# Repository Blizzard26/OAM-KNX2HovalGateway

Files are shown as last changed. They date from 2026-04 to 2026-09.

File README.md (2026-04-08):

# Hoval2KNXGateway

A KNX gateway for Hoval TopTronic systems, enabling integration between KNX home automation networks and Hoval CAN-based controllers.

It is a PlatformIO project and needs a working ETS 5.7 (or higher) installed on the same PC (at least for generating the required ETS files).

It uses some Modules from the OpenKNX project: OGM-Common, OFM-cnofigTransfer, OFM-FileTransferModule, OFM-LogicModule

## Description

This project implements a bridge between KNX protocol and Hoval's proprietary CAN-based communication protocol. It allows KNX devices to read and write parameters from Hoval TopTronic systems.

The gateway uses the Hoval Message Protocol over CAN bus at 50kbps, supporting both single and multi-part messages for comprehensive datapoint access.

## Supported Hardware

Currently supports

- Seeeduino XIAO RP2040 with a MCP2515 (and a support CAN Transceive, e.g. MCP2562). Make sure to electrically separate the KNX bus from the Hoval bus as the operate on different potentials.

## Software Requirements

- **PlatformIO**: For building and flashing the firmware
- **Git**: For cloning this repository
- **Arduino Framework**: Used via PlatformIO
- **Dependencies**:
  - KNX library (version 2.2.2+)
  - Seeed Arduino CAN library
  - Various OpenKNX modules

## Installation

1. Clone this repository and initialize submodules:
   ```bash
   git clone <repository-url>
   cd Hoval2KNXGateway
   git submodule update --init --recursive
   ```
   NOTE: In contrast to other OpenKNX Projects this project uses git submodule to pull in libraries instead of restore scripts and `dependencies.txt`.

2. Install PlatformIO if not already installed.

3. Install dependencies:
   ```bash
   pio lib install
   ```

## Building

Use the provided build scripts or PlatformIO directly:

### Development Build
```bash
scripts/Build-Release.ps1
```
Or use the VS Code task: `Build-Dev`

### Release Build
```bash
scripts/Build-Release.ps1 Release
```
Or use the VS Code task: `Build-Release`

### Configuration

- Configure KNX parameters using ETS (Engineering Tool Software)

### Monitoring

Connect to the serial port at 115200 baud for debug output and monitoring.

There are four new commands added:

- `hoval log message`: Log received and processed messages - header only.
- `hoval log messageData`: Log received and processed message - including (parsed) data.
- `hoval log filtered`: Log filtered message, i.e., messages not known to the decoder - header only.
- `hoval log filteredData`: Log filtered message - including raw data.

## Project Structure

- `src/`: Main source code
- `include/`: Header files and configuration
- `lib/`: Library dependencies and modules
- `docs/`: Protocol documentation (Hoval.adoc)
- `schematics/`: Hardware schematics in KiCad format
- `scripts/`: Build and utility scripts
- `test/`: Test files

## Documentation

Detailed protocol documentation is available in `docs/Hoval.adoc`, including:
- Message structure and addressing
- Function codes and datapoints
- Communication flow examples

## Contributing

1. Fork the repository
2. Create a feature branch
3. Make your changes
4. Test thoroughly
5. Submit a pull request

## License

GNU General Public License v3.0

## Support

For issues and questions:
- Check the debug logs via serial output
- Refer to the protocol documentation
- Ensure proper hardware connections

## Disclaimer

This software is provided as-is. Ensure compatibility with your specific Hoval system and KNX installation. Always backup configurations before making changes.

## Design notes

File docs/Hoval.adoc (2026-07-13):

= Hoval Message Protocol
:toc:
:toclevels: 4

== Overview
Hoval uses a CAN extended protocol with 50kbps as transport layer.
The session layer supports single and multi-part messages (messages consisting of several individual messages).

The Hoval Message Protocol is a CAN-based communication protocol with:

* 29-bit extended CAN identifiers (addressing)
* A message layer supporting:
  - Single messages (up to 8 bytes)
  - Multi-part messages (segmented payloads)
* A data model based on:
  - Function Code
  - Function Group
  - Function Number
  - Datapoint ID

Typical communication flow:

1. A device sends a request (e.g. read or write)
2. The target responds via broadcast
3. Messages may be single-frame or multi-part

Structure of a message:

`[Address (29 bit)] + [Payload (2–8 bytes)]`

Some information is not yet 100% clear. 
These parts are marked in #yellow#.

A lot of information can be found in the Modbus protocol description from Hoval (`TTE-GW-Modbus-datapoints.xlsx`). 

NOTE: This is not complete and there are many messages that are not documented.

=== Terminology

* Function Code: Defines the operation (read, write, etc.)
* Function Group: Logical grouping of datapoints
* Function Number: Sub-function within a group
* Datapoint ID: Unique identifier of a value
* Unit ID: Device identifier

Message Types:

* Single Message: Complete in one frame
* Multi-part Message:
  - Start Message
  - Intermediate Message(s)
  - End Message

=== Modbus Datapoints (from `TTE-GW-Modbus-datapoints.xlsx`)

*Modbus ID* +
Dec: 1 - 25610 +
Hex: 0x0001 - 0x640A +
Bits: 15

*Unit ID* +
Dec: 1 - 1160 +
Hex: 0x001 - 0x448 +
Bits: 11

*Function Group* +
Dec: 0 - 60 +
Hex: 0x00 - 0x3C +
Bits: 6

*Function Number* +
Dec: 0 - 254 +
Hex: 0x00 - 0xFE +
Bits: 8

*Datapoint ID* +
Dec: 0 - 40687 +
Hex: 0x0 - 0x9EEF +
Bits: 16

== Analysis of the message protocol

=== Address

The address consists of 29 bits (4 bytes) (Can extended protocol).

An address encodes:

* Sequence counter (multi-part only)
* Message type (single / multi-part)
* Sender Unit ID
* Target Unit ID

Example: `1F E0 42 08`

Structure (right to left):

* Bit 25 - 29: Multi-part message counter. This always starts at 0x1F (31) and counts down from there for multi-part messages.
** Messages with a 0 serve as timer messages/pings or similar.
* Bit 23-24: Message type:
** Bit 24 = 1: flag: last message in a multi-part message
** Bit 23 = 1: flag: first message in a multi-part message
* Bit 12 - 22: _Unit ID_ of the sender (device number + device type offset)
* Bit 11 - 1: _Unit ID_ of the target (device number + device type offset; see `TTE-GW-Modbus-datapoints.xlsx`) or `0x7FF` for broadcast

.Address Structure
====
Address: `1F E0 42 08`

[width="100%",cols="17%,17%,16%,17%,16%,17%",options="header",]
|===
| Byte 4 2+| Byte 3 2+| Byte 2 | Byte 1
| 1F 2+| E0 2+| 42 | 08
| Bit 29-25 | Bit 24-23 2+| Bit 12 - 22 2+| Bit 11 - 1
| 1 1111 | 11 | 10 0000 | 0100 0 | 010 | 0000 1000
|
0x1F +
Multi-part message counter +
31

|
0b11 +
Message Type +
First and last message (single message)

2+|
0x408 +
Unit ID (1024; BM ID 8)

2+|
0x208 +
Unit ID (520; HomeVent ID 8)

|===
====

==== Further examples

Multi-part message consisting of a first message, zero or more intermediate message and a last message  messages

- `1F5047FF` - `11111 01 01000001000 11111111111` - 31, first message, 0x208,
0x7FF
- `1E1047FF` - `11110 00 01000001000 11111111111` - 30, continuation, 0x208,
0x7FF
- `1D1047FF` - `11101 00 01000001000 11111111111` - 29, continuation, 0x208,
0x7FF
- `1C9047FF` - `11100 10 01000001000 11111111111` - 28, last message, 0x208,
0x7FF

Single request / response

- `1FE04208` - `11111 11 10000001000 01000001000` - 31, Single message, 0x408,
0x208
- `1FD047FF` - `11111 11 01000001000 11111111111` - 31, single message, 0x208,
0x7FF

==== Open points

Messages with the following addresses are currently not entirely clear

- `E047FF`
- `D047FF`

In particular, these have a message body that does not match the rest of the
pattern (0x0102).

These appear to be regular "pings". 
They occur every 5 seconds.

=== Message

A message consists of 2 to 8 bytes

There are different types of messages:

* Message type (bit 24+23) = 11: Single messages
* Message type (bit 24+23) <> 11: multi-part message.
* Special messages

==== Single message (message type 0b11)

A single message always has at least 6 bytes

* Byte 1: Always 0x01 (see start message)
* Byte 2: Function Code - see <<FunctionCodes>>
* Byte 3: 
** Bit 8: #Unknown.# Probably first bit of function group
** Bit 7-1: Function Group (see TTE-GW-Modbus-datapoints.xlsx)
* Byte 4: Function Number (see TTE-GW-Modbus-datapoints.xlsx) (8 bits)
* Byte 5 + 6: Datapoint ID (see TTE-GW-Modbus-datapoints.xlsx) (16 bit)
* Optional: Byte 7-8: Value (8-16 bits)

.Single Message
====
Message: `01 42 32 00 92 E2 00 E7``

[width="100%",options="header",]
|===
| Byte 1 | Byte 2 2+| Byte 3 | Byte 4 | Byte 5 | Byte 6 | Byte 7 | Byte 8

|01 |42 2+|32 | 00 |92 |E2 |00 |E7

| Always 0x01 

| Function Code 

| ?? +
0b0

| Function group +
(50)

| Function Number +
(0)

2+| Datapoint ID +
(37602)

2+|Value (45) |
|===
====

==== Multi-part Message
A multi-part message consist of a start message (containing the usual header + 1 data byte) and zero or more intermediate messages (containing a multi-part message id and up to 7 data byte) and an end message.

Start → Intermediate → ... → End

The last two bytes of the data seems to be some form of a CRC (cf. <<CRC>>).

Start message:

* Contains header + first data byte
* Defines total message count

Intermediate message:

* Contains message ID + data chunk

End message:

* Last chunk + CRC

.Multi-part Message
====
```
1F5047FFx 21 0F 42 00 00 71 72 03 
1E1047FFx 0F 00 FC 01 08 02 32 00 
1D1047FFx 0F F7 04 E4 AB 00 00 00 
1C9047FFx 0F 00 DF 58
```

* Header: `21 0F 42 00 00 71 72``
* Message ID: `0F`
* Body: `03 00 FC 01 08 02 32 00 F7 04 E4 AB 00 00 00 00`
* CRC: `DF 58`
====

===== Start messages (Message Type 0b01)

A start message always has exactly 8 bytes

* Byte 1:
** Bit 8-4: Number of messages in this multi-part message (incl. start and end message).
** Bit 3 - 1: #Unknown.# Always 0b001 in my case.
* Byte 2: Multi-part Message ID - identifier for related messages in multi-part message group.
Is increased per device by one with each message 
* Byte 3: 
** Bit 8: #Unknown.# Probably first bit of function code
** Bit 7-1: Function Code - see <<FunctionCodes>>
* Byte 4: Function group (see TTE-GW-Modbus-datapoints.xlsx)
* Byte 5: Function Number (see TTE-GW-Modbus-datapoints.xlsx) (8 bits)
* Byte 6 + 7: Datapoint ID (see TTE-GW-Modbus-datapoints.xlsx) (16
bit)
* Byte 8: Value (8 bits + continuation in further messages)

.Multi-part Message - Start Message
====
Message: `B9 1A 62 81 00 00 00 00`

[width="100%",cols="19%,13%,10%,10%,5%,12%,12%,6%,6%,7%",options="header",]
|===
2+| Byte 1 | Byte 2 2+| Byte 3 | Byte 4 | Byte 5 | Byte 6 | Byte 7 | Byte 8

2+|B9 |1A 2+|62 |81 |00 |00 |00 |00
| Bit 8-4 | Bit 3-1 | 2+| | | 2+| |
| 0b10111 | 0b001 | | 0b1 | 0b0000001 | | 2+| |

a|
Number of messages
(23)

| Unknown. Always 0b001. | Multi-part Message ID | ? |Function Code
| Function Group (1) 

a|
Function Number
(0)

2+a|
Datapoint ID
(0)

| Value (0)
|===
====

===== Intermediate messages (Message Type 0b00)

A continuation message has 2 - 8 bytes

* Byte 1: Message ID; taken from the start message (see above)
* Byte 2 - 8: Value

.Multi-part Message - End Message  (Message Type  0b10)
End message has the same structure as intermediate messages.

===== CRC

CRC properties (found by RevEng): width=16, poly=0x1021, init=0xb006, refin=true, refout=true, xorout=0x0000, check=0xff5a

[[FunctionCodes]]
=== Function Codes
The following function codes have been identified:

[width="100%",cols="15%,60%,20%",options="header",]
|===
| Function Code | Meaning | Direction

| 0x02 
| Ping/Announcement (every 5s). Body always 0x01 0x02 
| BM->HV & HV->BM

| 0x08 
| Unix time 
|

| 0x0A 
| Same message every 10s (0x02 0 208 0 408). Related to 0x50 
| HV-> (BM?)

| 0x30
| ?? Has something to do with changing IDs of BMs
|

| 0x31
| ?? Has something to do with changing IDs of BMs
|

| 0x40 
| Read addresses 
|

| 0x42 
| Send updated value (response to 0x40) 
|

| 0x44 
| Enable function (e.g. pause mode) 
|

| 0x46 
| Write new value to address 
|

| 0x4C 
| Every 10s (messages have repeating pattern; in connection with 0x50?) 
| HV->Broadcast

| 0x50 
| Same message every 10s (0x0 208 0 408). Related to 0x0A 
|

| 0x52 
| Every 10s (6 repeating messages; in connection with 0x42?); cf. <<special_messages_52>>
| BM->Broadcast

| 0x56 
| Error during reading (e.g. if sensor for reading not available) 
|

| 0x61 
| Every 7s 
| BM->Broadcast

| 0x62 
| Unknown 
| BM->HV

| 0x74 
| Every 5s (function group counts from 0-4; pattern repeats every 25s) 
| BM->Broadcast
|===

=== Reading a value

A request with function code `0x40` is sent from the interface to the Unit ID of the device.
In addition to the Function Code, the message contains the FunctionGroup, FunctionNumber and Datapoint ID of the value to be read.

The recipient responds with a broadcast (destination address 0x7FF). 
The message has the function code `0x42` and contains FunctionGroup, FunctionNumber and Datapoint ID as identifying features plus the value.
If an error occurs (e.g. because the sensor / value to be read is not available), the receiver responds with a message with Function Code `0x56`.

.Reading
====
Read Request

* Address: `1F E0 42 08` 
* Message Content: `01 42 32 00 92 E2`

-> Function Code: 0x40, Function Group: 0x32, Function Number: 0x00, Datapoint ID: 0x92E2

Response:

* Address `1F D0 47 FF`
* Message Content: `01 42 32 00 92 E2 00 E7`

-> Function Code: 0x42, Function Group: 0x32, Function Number: 0x00, Datapoint ID: 0x92E2, Value: 0x00E7
====

=== Writing a value

The interface sends a request with function code `0x46` to the Unit ID of the device. 
In addition to the Function Code, the message contains the FunctionGroup, FunctionNumber and Datapoint ID as identifying features.
The new value is sent in the value bytes of the single or multi-part message.

The receiver responds with a broadcast (destination address 0x7FF). 
The message has the function code `0x42` and contains FunctionGroup, FunctionNumber and Datapoint ID as identifying features plus the (new) value.

.Writing
====
Write Request:

* Address: `1F E0 42 08`
* Message Content: `01 46 32 00 96 CE`

Function Code 0x46, Function Group 0x32, Function Number: 0x00, Datapoint ID: 0x96CE, New Value: 0x2D

Response:

* Address: `1F D0 47 FF`
* Message Content: `01 42 32 00 96 CE 2D`

Function Code 0x42, Function Group 0x32, Function Number: 0x00, Datapoint ID: 0x96CE, New Value: 0x2D
====

=== Special messages

There are a number of messages that do not correspond to the "normal" pattern:

[width="100%",cols="15%,25%,30%,40%",options="header"]
|===
| Address  | Address Structure | Data | Meaning

|   E047FF | 0b11 #0x408# 0x7FF | 0x01 02                 | (every 5s; from BM)
|   D047FF | 0b11  0x208  0x7FF | 0x01 02                 | (every 5s; from HV)
|   D047FF | 0b11  0x208  0x7FF | 0x01 0A 02 02 08 04 08  | (every 10s)
| 1FD047FF | 0b11  0x208  0x7FF | 0x01 4C 0F 01 00        | (every 10s)
| 1FD047FF | 0b11  0x208  0x7FF | 0x01 50 02 08 04 08     | (every 10s)
| 1FE047FF | 0b11 #0x408# 0x7FF | 0x01 52 06 01 00        | (every 10s)
| 1FD047FF | 0b11  0x208  0x7FF | 0x01 61 ** FF           | (every 7s)
| 1FE047FF | 0b11 #0x408# 0x7FF | 0x01 61 ** FF           | (every 7s)
|===

Current time in Unix time

* `1FD047FF - `01 08 5F 13 76 0D``

[[special_messages_52]]
==== Sequence 0x52 -> 0x4C every 10s
Function Codes 0x52 and 0x4C follow a sequence. 
In particular, there is one sequence of 6 message for function code 0x52 from the BM to broadcast:
```
01 52 00 01 00
01 52 01 02 00 64
01 52 02 04 FF FF FF FF
01 52 03 02 13 0E
01 52 04 02 03 96
01 52 06 01 00
```

And there is a sequence of 15 messages for function code 0x4C from HV to broadcast:
```
01 4C 02 02 80 00
01 4C 0B 01 80
01 4C 05 01 80
01 4C 01 02 80 00
01 4C 0A 01 80
01 4C 04 01 80
01 4C 13 01 00
01 4C 11 01 00
01 4C 08 01 80
01 4C 0E 01 80
01 4C 07 01 80
01 4C 0D 01 80
01 4C 12 01 00
01 4C 14 01 00
01 4C 0F 01 00
```

It actually doesn't seem to be a request reply pattern, because sometimes there is not message from the other side, but the pattern keeps just going on.
There is a gap of 4 messages on the 0x4C side every 15 message on the 0x52 side. 

==== Function Code 0x61
Repeating sequence of message from BM to Broadcast.
Next message from sequence is send every 7 seconds.

Sequence:
----
01 61 00 FF
01 61 50 FF FF
01 61 51 FF
01 61 52 FF
01 61 53 FF
01 61 54 FF FF
01 61 55 FF
01 61 57 FF
01 61 58 FF
01 61 59 FF
01 61 5A FF
01 61 5B FF FF FF FF
----

==== Function Code 0x62
Repeating sequence of messages from BM to Broadcast. Message Sequence is send every 10 minutes in short succession of about 50ms.

Sequence:
----
01 62 06 32 00 E0 92
01 62 06 32 00 E2 92
01 62 06 32 00 C8 96
----

==== Function Code 0x72
Multi-part Message sequence. 
Each message consists of two parts.
Next message of the sequence is send every 5 seconds.

Sequence:
----
11 * 74 00 FF 00 00 00 00 FF FF 71 E5
11 * 74 01 FF 00 00 00 00 FF FF F0 5A
11 * 74 02 FF 00 00 00 00 FF FF 7A 8A
11 * 74 03 FF 00 00 00 00 FF FF FB 35
11 * 74 04 FF 00 00 00 00 FF FF 67 3B
----
`*` Is replaced by the multi-part message id

== Function Groups

TODO Copy function groups from Excel

=== Undocumented function groups

During my tests, I was able to observe a whole series of function groups
which are not documented in `TTE-GW-Modbus-datapoints.xlsx`:

* 6
* 7
* 8
* 18
* 19
* 61 - Weekly program?
* 62 - Daily program?
* 66

== Datapoint ID

=== Undocumented Datapoint IDs

During my tests I was able to observe a whole series of datapoints, which are not documented in TTE-GW-Modbus-datapoints.xlsx.
I was able to identify some of them:

[width="100%",cols="12%,6%,11%,11%,12%,42%,6%",options="header"]
|===
| Unit Name | Unit ID | Function-Group | Function-Number | Datapoint-ID | Datapoint Name | Type

| HV | 513-528 | 50 | 0 | 2010 | Timer Party Mode (time in hours x 10; e.g., 25 = 2.5h) | U8

| HV | 513-528 | 50 | 0 | 2018 | Timer pause mode (time in hours x 10; e.g., 25 = 2.5h) | U8

| HV | 513-528 | 0 | 0 | 21054 | Reset Maintenance Counter; defaults to 0x00, function code 0X46 with body 0x07 does a reset | U8

| HV | 513-528 | 0 | 0 | 21058 | remaining time of maintenance counter (operating weeks); byte 3 is remaining weeks | RAW

| HV | 513-528 | 0 | 0 | 20037 | maintenance counter message maintenance (operating weeks); byte 3 is remaining weeks | RAW
|===

== Data Structures

=== Active Errors
The following Datapoints contain information about active errors

[width="100%",cols="20%,20%,20%,40%",options="header"]
|===
| Function Group | Function Number | Datapoint ID | Name

| 0 | 0 | 29042 | Active Error 1 
| 0 | 0 | 29043 | Active Error 2
| 0 | 0 | 29044 | Active Error 3 
| 0 | 0 | 29045 | Active Error 4 
| 0 | 0 | 29046 | Active Error 5
|===

Error Message are a multi-part message with 18 bytes with the following structure:

[width="100%",cols="20%,80%",options="header"]
|===
| Byte | Content

| 0	 a| error_type + 
log level, displayed as char where 3 = W, 4 = E ...
#WARNING: This is not really correct. I've seen an 8 for a warning.#
| 1	 | ?? - maybe high byte of error_type, but error type is defined as uint8
| 2	 .2+| error_code (low byte, high byte)
| 3	 
| 4	 .2+| source (low byte, high byte)
| 5	 
| 6	 | function_group
| 7	 | function_number
| 8	 .2+a| start_time (low byte, high byte) +
 time since midnight
| 9	 
| 10 .2+a| start_date (low byte, high byte) +
 date since 01.01.1900
| 11 
| 12 .2+a| end_time (low byte, high byte) +
 time since midnight
| 13 
| 14 .2+a| end_date (low byte, high byte) +
 date since 01.01.1900
| 15 
| 16 .2+a| CRC 
| 17
|===

.Error Message
====
Message: `03 00 FC 01 08 02 32 00 F7 04 E4 AB 00 00 00 00 DF 58`

[width="100%",cols="20%,80%",options="header"]
|===
| Bytes | Meaning

| 03    | Error level W
| 00    |
| FC 01 | error code 508
| 08 02 | source 0x208 (Homevent)
| 32    | function group 50
| 00    | function number 0
| F7 04 | 0x04F7 = 1271 minutes since midnight -> 21:11 o'clock
| E4 AB | 0xABE4 = 44004 days since 01.01.1900 -> 23.06.2020
| 00 00 | no end time - error still active
| 00 00 | no end date - error still active
| DF 58 | CRC
|===
====

After confirming a warning, the following message was send for some time: `B4 34 00 20 40 00 00 00 72 71 01 00 00 00 00 00`

[width="100%",cols="20%,80%",options="header"]
|===
| Bytes | Meaning

| B4    | ??
| 34    | ??
| 00 20 | 0x0200 (8192)
| 40 00 | source 0x0040 (64)
| 00    | function group 0
| 00    | function number 0
| 72 71 | 0x7172 = ??
| 01 00 | 0x0001 = ??
| 00 00 | no end time - error still active
| 00 00 | no end date - error still active
|===

=== Known Error Codes

[width="100%",cols="10%,10%,20%,60%",options="header"]
|===
| Error Type | Error Code | Displayed Code |Meaning

| 8 | 511 | W:511 |The heat generator is indicating that cleaning is required

|===

== Examples
=== Read Exhaust air temp

* Device type: 513 - 528 (HV); 512 + device address
* Device address: 8
* Function group: 50
* Function Number: 0
* Datapoint ID: 37602

[width="100%",cols="10%,20%,24%,24%,22%",options="header",]
|===
| | Unit ID (11 bit) | Function group (6 bits) | Function Number (8 bit) | Datapoint ID (16 bit)
| DEC |512 + 8 |50 |0 |37602
| HEX |0x208 |0x32 |0x00 |0x92 0xE2
|===

*Read Request*

* Sender: |Unit ID(1032)| --> BM 8
* Destination: |Unit ID(520)| --> HV 8
* Function Code: `0x40`

* Address: `1F E 04 208` 
* Message Content: `01 42 32 00 92 E2`

[width="100%",options="header",]
|===
|      | Function Code | Function Group | Function Number 2+| Datapoint ID 
| 0x01 | 0x40 | 0x32        | 0x00       | 0x92 | 0xE2 
| 00000001 | 01000010 | 110010 | 00000000 | 10010010 | 11100010 
|===

*Response*

Address `1F D 04 7FF`

* Sender: |Unit ID(520)| --> HV 8
* Destination: Broadcast
* Function Code: `0x42`

Message Content: `01 42 32 00 92 E2 00 E7`

[width="99%",cols="16%,11%,15%,14%,11%,11%,11%,11%",options="header",]
|===
| | Function Code |Function Group | FunctionNumber 2+| Datapoint ID  2+| Value (231)

|0x01 |0x42 |0x32 |0x00 |0x92 |0xE2 |0x00 |0xE7
|00000001 |01000010 |110010 |00000000 |10010010 |11100010 |00000000 |11100111
|===

=== Write Ventilation modulation

* Device type: 513 - 528 (HV); 512 + device address
* Device address: 8
* Function group: 50
* Function Number: 0
* Datapoint ID: 38606

[width="99%",cols="10%,21%,24%,24%,21%",options="header",]
|===
| | Unit ID (11 bit) | Function group (6 bits) | Function Number (8 bit) | Datapoint ID (16 bit)

| DEC | 512 + 8 | 50 | 0 | 38606
| HEX | 0x208 | 0x32 | 0x00 | 0x92 0xCE
|===

*Write Request:*

* Sender: |Unit ID(1032)| --> BM 8
* Destination: |Unit ID(520)| --> HV 8
* Function Code: `0x46``

* Address: `1F E 04 208`
* Message Content: `01 46 32 00 96 CE`

[width="99%",cols="16%,13%,17%,15%,13%,13%,13%",options="header",]
|===
|     | Function Code | Function Group | Function Number 2+| Datapoint ID |Value (45)
|0x01 |0x46 |0x32 |0x00 |0x96 |0xCE |0x2D
|00000001 |01000010 |00110010 |00000000 |10010110 |11001110 |00101101
|===

*Response:*

Address: `1F D 04 7FF`

* Sender: |Unit ID(520)| -→ HV 8
* Destination: Broadcast
* Function Code: `0x42`

Message Content: `01 42 32 00 96 CE 2D`

[width="99%",cols="16%,13%,17%,15%,13%,13%,13%",options="header",]
|===
|     | Function Code | Function Group | Function Number 2+| Datapoint ID |Value (45)
|0x01 |0x42 |0x32 |0x00 |0x96 |0xCE |0x2D
|00000001 |01000010 |00110010 |00000000 |10010110 |11001110 |00101101
|===

== Open Questions

The following parts are not fully understood:

- Bit 3–1 in start message (always 0b001)
- Function Codes 0x30, 0x31
- Special ping messages (E047FF, D047FF)
- Exact Structure of Errors (especially level)

== Special Function Codes

=== Function Code 74

The following pattern is repeated every 25s
[width="99%",cols="20%,16%,16%,16%,16%,16%",]
|===
|Sender |Receiver |Function group |Function Number |Datapoint ID
|Value

|BM8 |Broadcast |0 |255 |0 |0

|HV8 |Broadcast |0 |3 |58479 |242

|BM8 |Broadcast |1 |255 |0 |0
|HV8 |Broadcast |1 |180 |0 |0

|BM8 |Broadcast |2 |255 |0 |0

|HV8 |Broadcast |2 |0 |0 |0

|BM8 |Broadcast |3 |255 |0 |0

|HV8 |Broadcast |3 |0 |0 |0

|BM8 |Broadcast |4 |255 |0 |0

|HV8 |Broadcast |4 |0 |0 |0
|===

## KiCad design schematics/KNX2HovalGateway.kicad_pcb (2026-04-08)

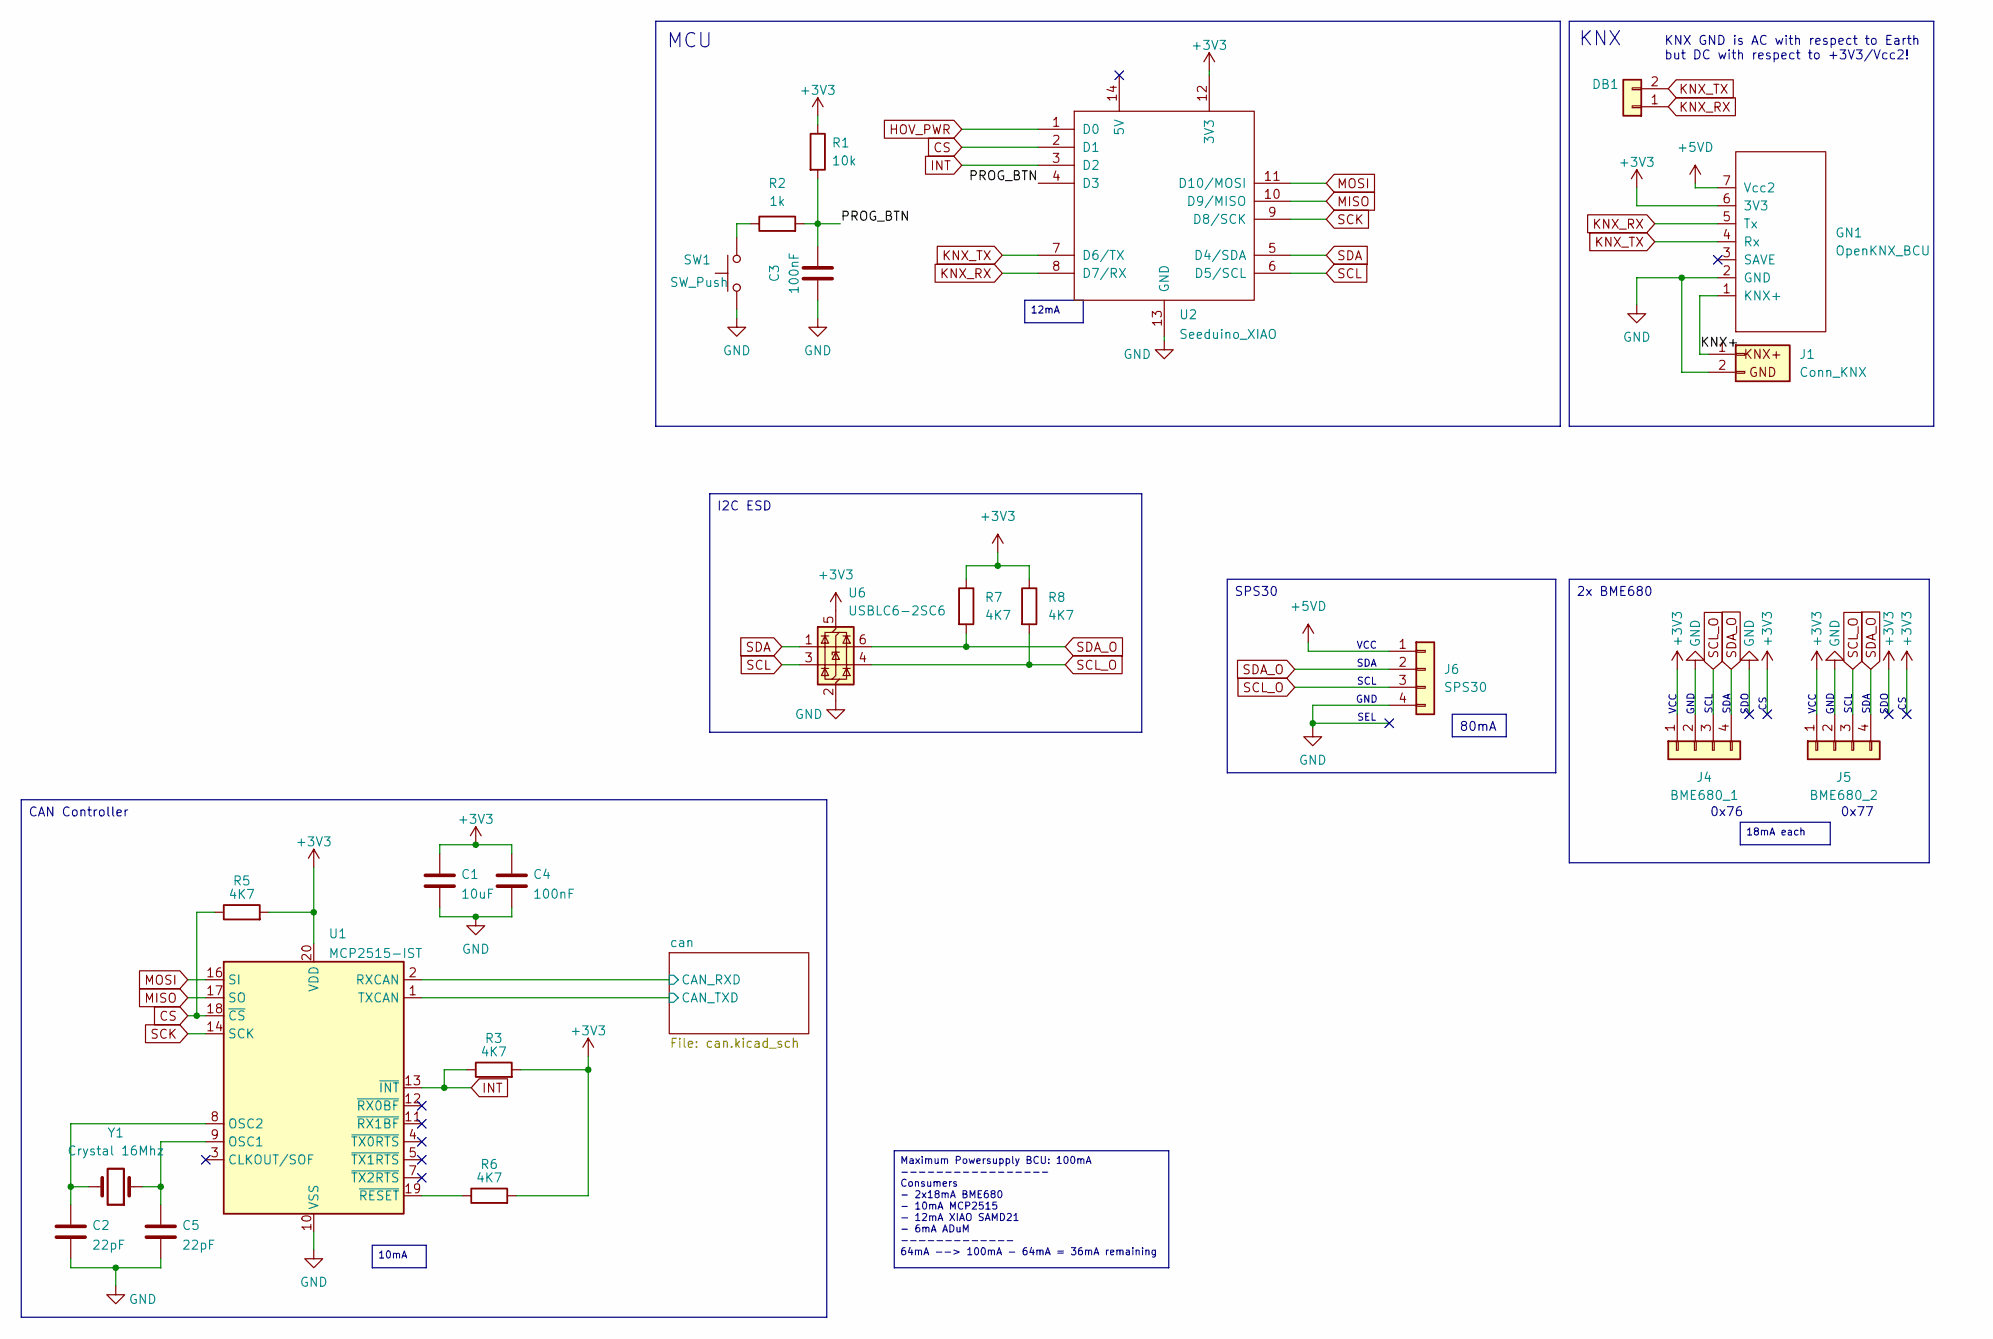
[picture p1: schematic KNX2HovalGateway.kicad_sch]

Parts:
C1: 10uF; C_0603_1608Metric_Pad1.08x0.95mm_HandSolder
C2, C5: 22pF; C_0603_1608Metric_Pad1.08x0.95mm_HandSolder
C3, C4: 100nF; C_0603_1608Metric_Pad1.08x0.95mm_HandSolder
DB1: Conn_01x02; PinHeader_1x02_P2.54mm_Vertical
GN1: OpenKNX_BCU; NanoBCU_Soldered
J1: Conn_KNX; KNX_Connector
J4: BME680_1; Molex_SL_171971-0004_1x04_P2.54mm_Vertical
J5: BME680_2; Molex_SL_171971-0004_1x04_P2.54mm_Vertical
J6: SPS30; Molex_SL_171971-0004_1x04_P2.54mm_Vertical
R1: 10k; R_0603_1608Metric_Pad0.98x0.95mm_HandSolder
R2: 1k; R_0603_1608Metric_Pad0.98x0.95mm_HandSolder
R3, R5, R6, R7, R8: 4K7; R_0603_1608Metric_Pad0.98x0.95mm_HandSolder
SW1: SW_Push; B3FS-1000
U1: MCP2515-IST; TSSOP-20_4.4x6.5mm_P0.65mm
U2: Seeduino_XIAO; XIAO-RP2040-DIP
U6: USBLC6-2SC6; SOT-23-6
Y1: Crystal 16Mhz; Crystal_SMD_5032-2Pin_5.0x3.2mm_HandSoldering

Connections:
+3V3: C1.1, C4.1, GN1.6 (3V3), J4.1, J5.1, R1.1, R3.2, R5.2, R6.2, R7.1, R8.1, U1.20 (VDD), U2.12 (3V3), U6.5 (VBUS); also elsewhere on the board
+5VD: GN1.7 (Vcc2), J6.1
/KNX+: GN1.1 (KNX+), J1.1
/PROG_BTN: C3.2, R1.2, R2.2, U2.4 (D3)
/can/CAN_RXD: U1.2 (RXCAN); also elsewhere on the board
/can/CAN_TXD: U1.1 (TXCAN); also elsewhere on the board
CS: R5.1, U1.18 (~CS), U2.2 (D1)
GND: C1.2, C2.2, C3.1, C4.2, C5.2, GN1.2 (GND), J1.2, J4.2, J5.2, J6.4, SW1.1, U1.10 (VSS), U2.13 (GND), U6.2 (GND); also elsewhere on the board
HOV_PWR: U2.1 (D0); also elsewhere on the board
INT: R3.1, U1.13 (~INT), U2.3 (D2)
KNX_RX: DB1.1, GN1.5 (Tx), U2.8 (D7/RX)
KNX_TX: DB1.2, GN1.4 (Rx), U2.7 (D6/TX)
MISO: U1.17 (SO), U2.10 (D9/MISO)
MOSI: U1.16 (SI), U2.11 (D10/MOSI)
unnamed: R2.1, SW1.2
unnamed: C5.1, U1.9 (OSC1), Y1.1
unnamed: C2.1, U1.8 (OSC2), Y1.2
unnamed: R6.1, U1.19 (~RESET)
SCK: U1.14 (SCK), U2.9 (D8/SCK)
SCL: U2.6 (D5/SCL), U6.3 (I/O2)
SCL_O: J4.3, J5.3, J6.3, R8.2, U6.4 (I/O2)
SDA: U2.5 (D4/SDA), U6.1 (I/O1)
SDA_O: J4.4, J5.4, J6.2, R7.2, U6.6 (I/O1)

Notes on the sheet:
SCL
SDO
SDA
0x76
GND
0x77
VCC
KNX
SEL
KNX GND is AC with respect to Earth but DC with respect to +3V3/Vcc2!
I2C ESD
SPS30
2x BME680
CAN Controller
80mA
18mA each
12mA
Maximum Powersupply BCU: 100mA ----------------- Consumers - 2x18mA BME680 - 10mA MCP2515 - 12mA XIAO SAMD21 - 6mA ADuM ------------- 64mA --> 100mA - 64mA = 36mA remaining
MCU
10mA

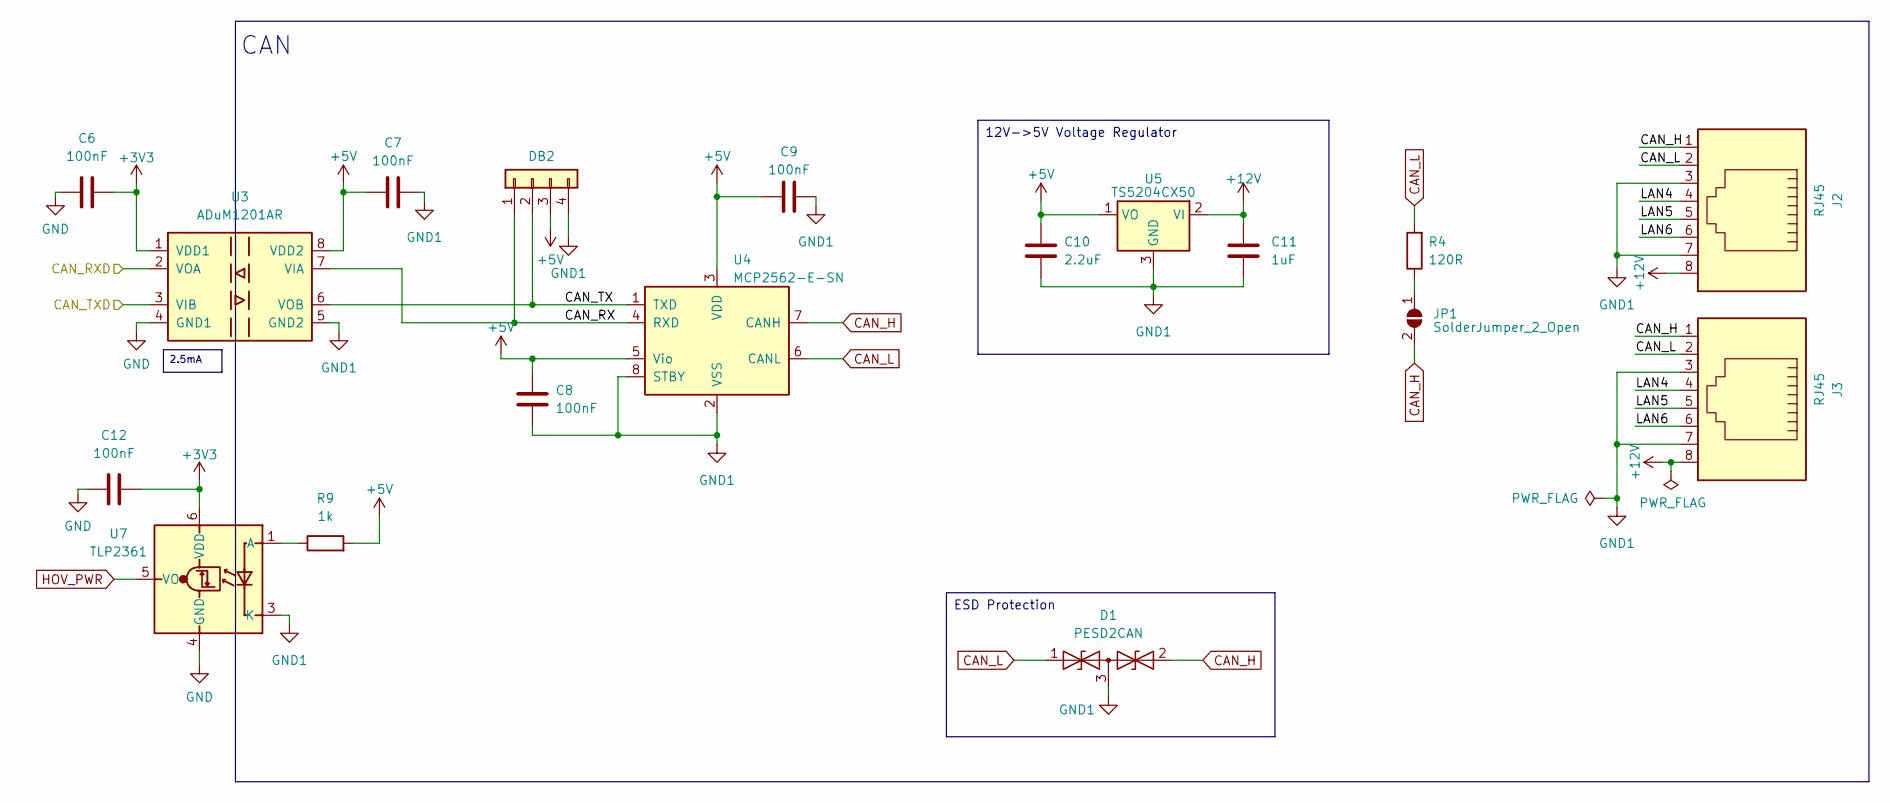
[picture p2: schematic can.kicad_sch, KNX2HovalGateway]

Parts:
C6, C7, C8, C9, C12: 100nF; C_0603_1608Metric_Pad1.08x0.95mm_HandSolder
C10: 2.2uF; C_0603_1608Metric_Pad1.08x0.95mm_HandSolder
C11: 1uF; C_0603_1608Metric_Pad1.08x0.95mm_HandSolder
D1: PESD2CAN; SOT-23
DB2: Conn_01x02; PinHeader_1x04_P2.54mm_Vertical
J2, J3: RJ45; RJ45_Ninigi_GE
JP1: SolderJumper_2_Open; SolderBridge
R4: 120R; R_0603_1608Metric_Pad0.98x0.95mm_HandSolder
R9: 1k; R_0603_1608Metric_Pad0.98x0.95mm_HandSolder
U3: ADuM1201AR; SOIC-8_3.9x4.9mm_P1.27mm
U4: MCP2562-E-SN; SOIC-8_3.9x4.9mm_P1.27mm
U5: TS5204CX50; SOT-23-3
U7: TLP2361; Toshiba_SOIC-5-6_4.4x3.6mm_P1.27mm

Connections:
+3V3: C6.2, C12.2, U3.1 (VDD1), U7.6 (VDD); also elsewhere on the board
+5V: C7.1, C8.2, C9.1, C10.1, DB2.3, R9.2, U3.8 (VDD2), U4.3 (VDD), U4.5 (Vio), U5.1 (VO)
+12V: C11.1, J2.8, J3.8, U5.2 (VI)
/can/CAN_RX: DB2.1, U3.7 (VIA), U4.4 (RXD)
/can/CAN_RXD: U3.2 (VOA); also elsewhere on the board
/can/CAN_TX: DB2.2, U3.6 (VOB), U4.1 (TXD)
/can/CAN_TXD: U3.3 (VIB); also elsewhere on the board
/can/LAN4: J2.4, J3.4
/can/LAN5: J2.5, J3.5
/can/LAN6: J2.6, J3.6
CAN_H: D1.2 (A2), J2.1, J3.1, JP1.2 (B), U4.7 (CANH)
CAN_L: D1.1 (A1), J2.2, J3.2, R4.2, U4.6 (CANL)
GND: C6.1, C12.1, U3.4 (GND1), U7.4 (GND); also elsewhere on the board
GND1: C7.2, C8.1, C9.2, C10.2, C11.2, D1.3 (common), DB2.4, J2.3, J2.7, J3.3, J3.7, U3.5 (GND2), U4.2 (VSS), U4.8 (STBY), U5.3 (GND), U7.3 (K)
HOV_PWR: U7.5 (VO); also elsewhere on the board
unnamed: JP1.1 (A), R4.1
unnamed: R9.1, U7.1 (A)

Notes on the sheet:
CAN
ESD Protection
2.5mA
12V->5V Voltage Regulator

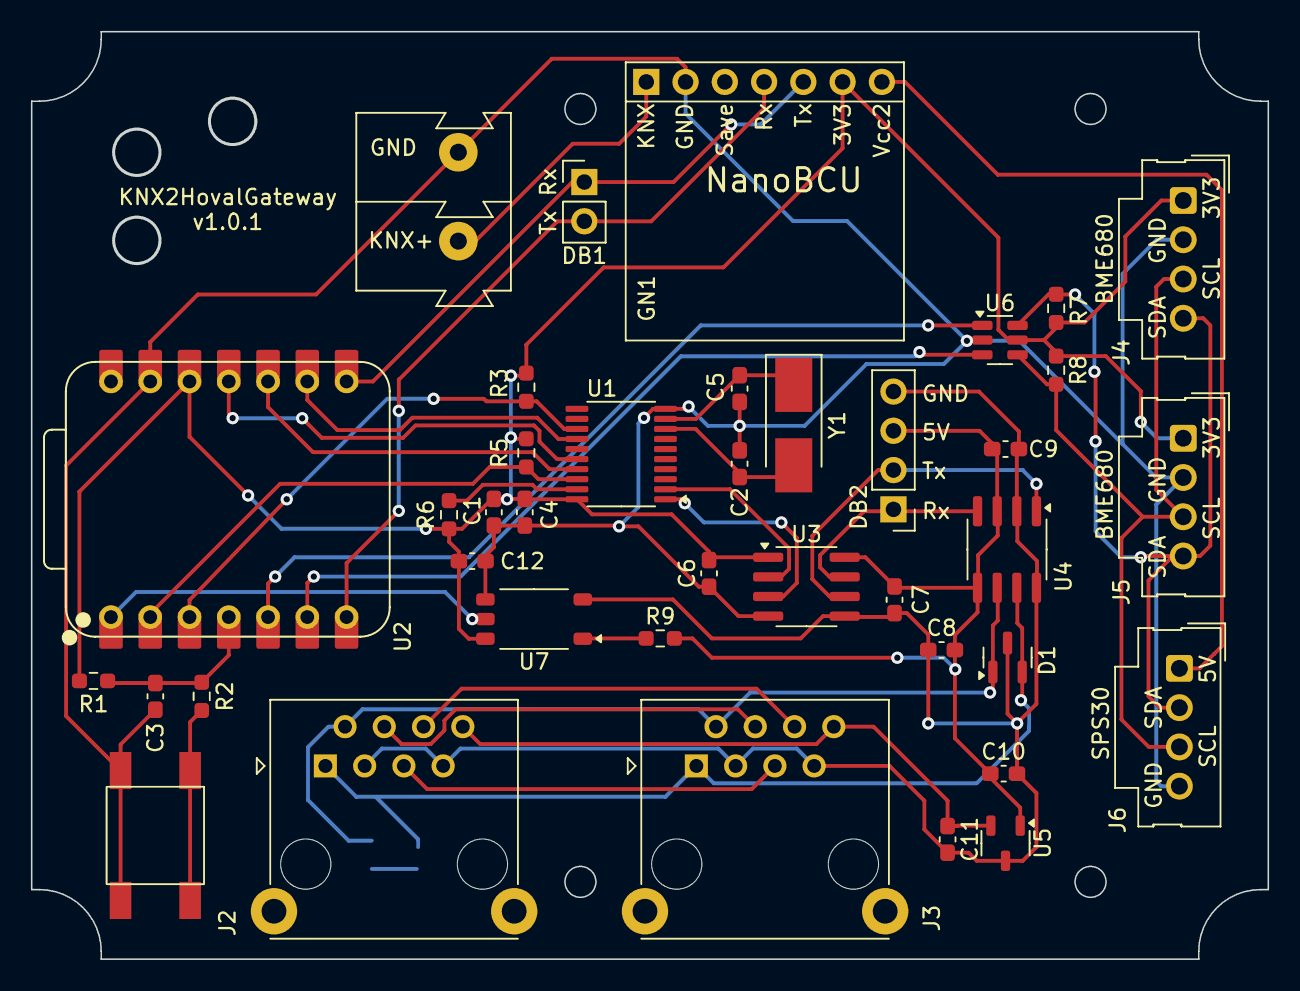
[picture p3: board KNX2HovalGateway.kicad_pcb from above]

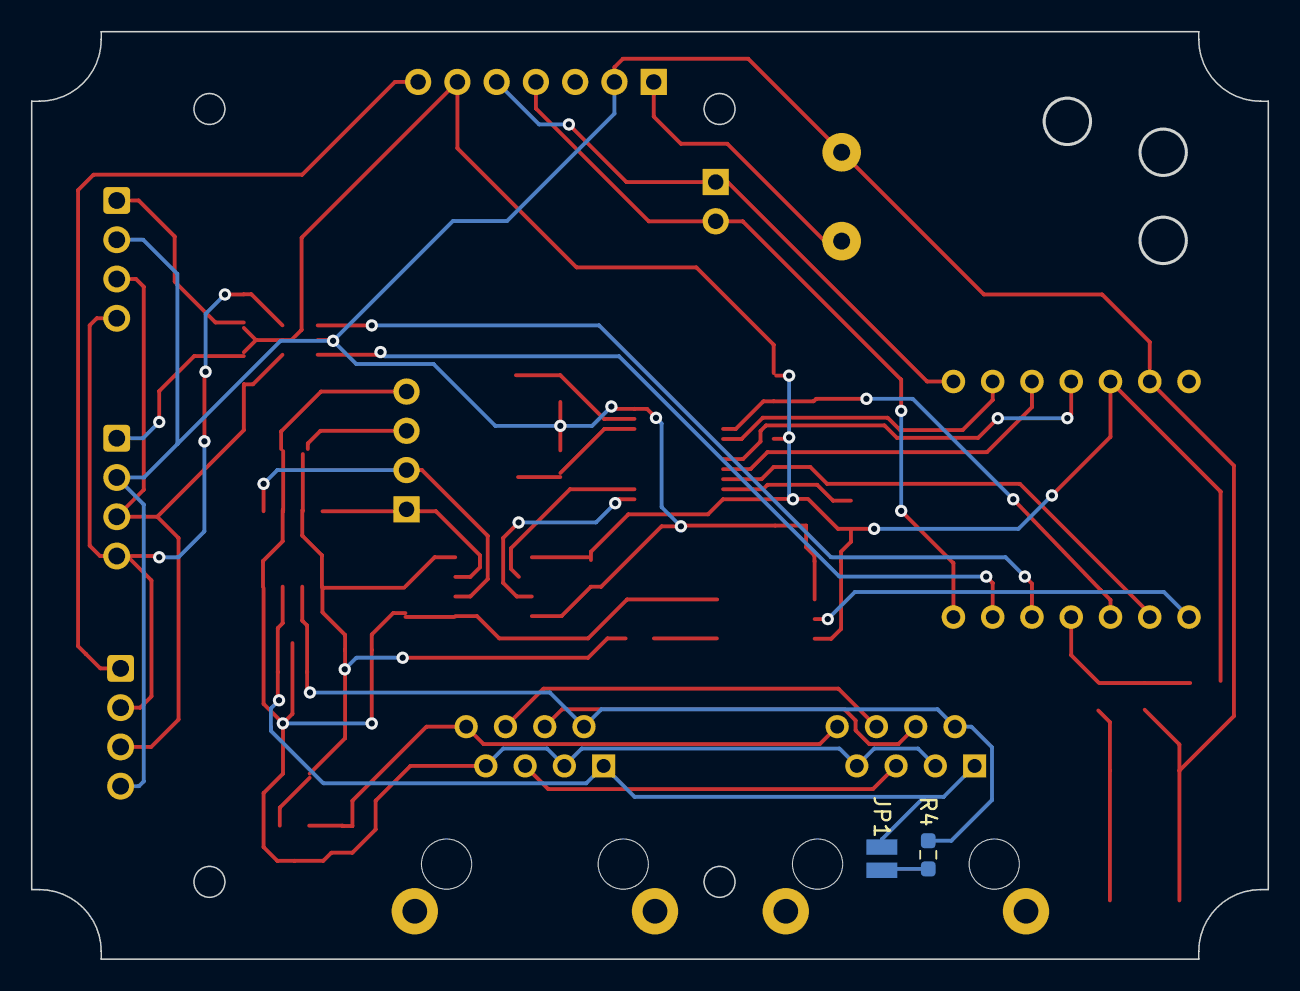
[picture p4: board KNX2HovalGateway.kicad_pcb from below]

Board: 2 copper layers, 80.0 x 60.0 mm, 41 parts (2 on the bottom side), 35 nets.

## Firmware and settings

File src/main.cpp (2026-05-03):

#include "hardware.h"
#include <Arduino.h>

#include "FileTransferModule.h"
#include "Logic.h"
#include <knx.h>

#include "knxprod.h" // Needs to be included after knx.h

#include "HovalGatewayModule.h"

////////////////////////
// Global Variables
////////////////////////

Knx2HovalGatewayModule hovalGatewayModule;

void setup()
{
  // Start debug serial with 115200 bauds
  Serial.begin(115200);

  openknx.init();

  openknx.addModule(1, hovalGatewayModule);
  openknx.addModule(3, openknxLogic);
  openknx.addModule(9, openknxFileTransferModule);

  openknx.setup();
}

void loop()
{
  openknx.loop();
}

#if defined(OPENKNX_DUALCORE)

void setup1()
{
  openknx.setup1();
}

void loop1()
{
  openknx.loop1();
}

#endif

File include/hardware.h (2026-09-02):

// Hier stehen alle Hardwarespezifischen defines
#pragma once

#if defined(ARDUINO_SEEED_XIAO_RP2040)
// Arduino XIAO RP20240
// OpenKNX defines
#define KNX_DEBUG_SERIAL Serial
#define KNX_SERIAL Serial1 // D7=RX/D6=TX

#define PROG_LED_PIN PIN_LED_B
#define PROG_LED_PIN_ACTIVE_ON LOW
#define INFO1_LED_PIN PIN_LED_G
#define INFO1_LED_PIN_ACTIVE_ON LOW
#define INFO2_LED_PIN PIN_LED_R
#define INFO2_LED_PIN_ACTIVE_ON LOW

#define PROG_BUTTON_PIN D3
#define PROG_BUTTON_PIN_INTERRUPT_ON FALLING
//
// #define SAVE_INTERRUPT_PIN 5
#define KNX_UART_RX_PIN D7
#define KNX_UART_TX_PIN D6
#define KNX_UART_NUM 0

// Application Custom defines
#define DEBUGSERIAL Serial // USB port

#define SPI_CS_PIN D1

#define CAN_SPI SPI
#define CAN_INT_PIN D2
#define CAN_CLOCK MCP_16MHz

#define HOVAL_ACTIVE_PIN D0
#define HOVAL_ACTIVE_PIN_ACTIVE_ON LOW

#else
#error Unsupported board
#endif

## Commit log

2026-04-08 Add analysis and description of Hoval Protocol
    This reverts commit 00ff4016ebb15c968af8bb68b50861c8e50a1ba1.
    [TTE-GW-Modbus-datapoints.xlsx]
2026-04-08 Add Schematics for KNX2HovalGateway
    [KNX2HovalGateway.kicad_pcb, KNX2HovalGateway.kicad_sch, can.kicad_sch]
2026-05-03 Switch to simple loop
2026-05-03 Replace ifndef by pragma once
    [hardware.h]
2026-09-02 Give sendBuffer explicit ownership via std::unique_ptr
    Raw HovalMessage* pointers in sendBuffer required delete calls at four
    scattered sites, so a future exit path could silently leak. Switching
    the buffer to std::unique_ptr<HovalMessage> and SimpleRingBuffer's
    push/offer to move-assignment makes ownership enforced by the type
    instead of by convention.
2026-09-02 Introduce CanTransport abstraction and wire it into HovalProtocolHandler
    Replaces the direct MCP_CAN* coupling in HovalProtocolHandler/Knx2HovalGatewayModule
    with a CanTransport interface, implemented for RP2040 by Mcp2515IsrCanTransport, which
    drives the MCP2515 via a real attachInterrupt() ISR instead of polling. This should
    hopefully fix the CAN overflow issue by buffering bursts internally and surfacing
    drops via CanErrorInfo.overflowDetected.
    [hardware.h]
